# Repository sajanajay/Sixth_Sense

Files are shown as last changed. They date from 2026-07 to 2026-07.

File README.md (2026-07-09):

<div align="center">

# 🚴 Sixth Sense

### Intelligent Rear-Collision Warning System for Cyclists

*A radar-powered embedded safety system that gives cyclists a new sense of awareness through intuitive haptic feedback.*

Github_Cover

**Engineering Design Project**

Department of Electronic & Telecommunication Engineering  
University of Moratuwa







</div>

---

# The Problem

Every cyclist knows the feeling.

You're riding with your eyes fixed ahead.

Then...

A vehicle approaches rapidly from behind.

Do you look over your shoulder?

Do you trust your hearing?

Do you hope nothing is beside you?

That split second of uncertainty is exactly where accidents happen.

**Sixth Sense was created to eliminate that uncertainty.**

---

# Introducing Sixth Sense

Sixth Sense is a radar-assisted cyclist safety system that continuously monitors approaching traffic behind the rider and instantly communicates danger through directional haptic feedback.

Instead of distracting screens or loud warning sounds, the system speaks through touch.

Left side approaching?

👉 Left handlebar vibrates.

Right side approaching?

👉 Right handlebar vibrates.

Directly behind?

👉 Both handlebars respond.

The rider never needs to take their eyes off the road.

---

# Demo

## 🎥 Demo

<p align="center">
  <a href="https://drive.google.com/file/d/1ffC6w6P3MY6zFnOaW4FhN-ex5IwfBISE/view?usp=drive_link">
    Watch Demo
  </a>
</p>

## 🎥 PCB Functionality Testing

<p align="center">
  <a href="https://drive.google.com/drive/folders/12CS2pHYX-PVSih4xlRxphCRVApFPQM8z?usp=sharing">
    Watch Testing
  </a>
</p>

<p align="center">
<b>▶ Click the image above to watch the demonstration</b>
</p>
# Product Showcase

## Complete System

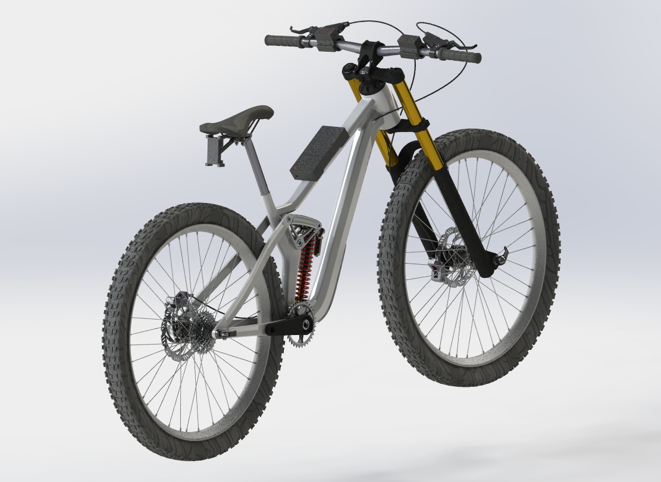
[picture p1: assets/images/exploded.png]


## Mounted on Bicycle

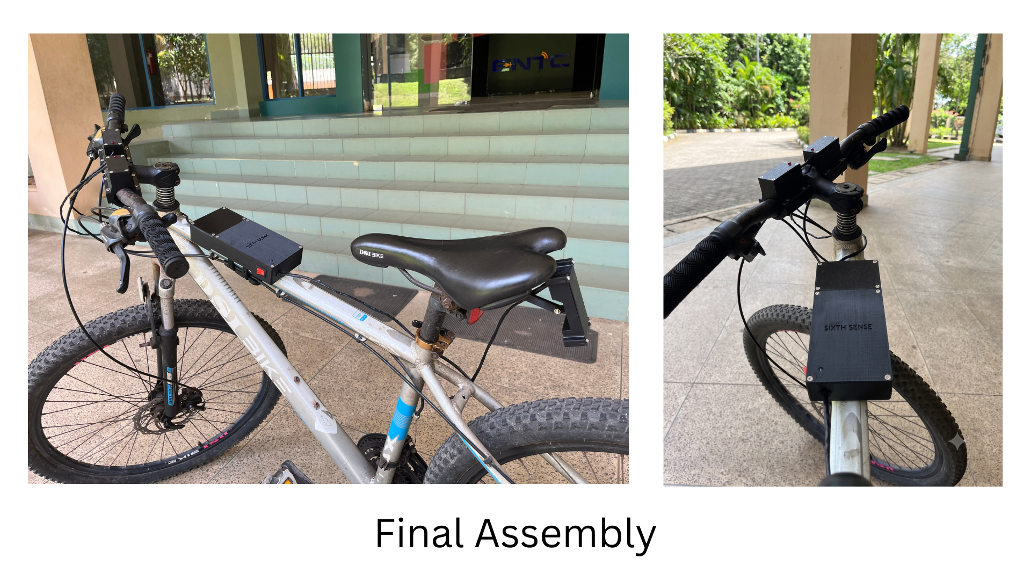
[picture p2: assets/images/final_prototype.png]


# Key Features

✔ 24 GHz FMCW mmWave Radar

✔ Intelligent Rear Vehicle Detection

✔ Real-Time Embedded Processing

✔ Directional Haptic Feedback

✔ Visual LED Warning System

✔ Custom Designed PCB

✔ ESP32 Embedded Platform

✔ Battery Powered

✔ Modular Hardware Design

✔ Custom CAD Enclosures

✔ 3D Printed Prototype

✔ Lightweight Bicycle Integration

# How It Works

```text
          Vehicle

             │

             ▼

      24 GHz Radar Sensor

             │

             ▼

      ESP32 Embedded System

             │

   Threat Evaluation Logic

             │

    ┌────────┴────────┐

    ▼                 ▼

 Left Handle     Right Handle

 Haptic Unit     Haptic Unit

    ▼                 ▼

 Rider receives intuitive tactile warning
```

# System Architecture



# Hardware Overview

## Rear Radar Module

Captures approaching vehicles using 24 GHz FMCW radar technology.

📷

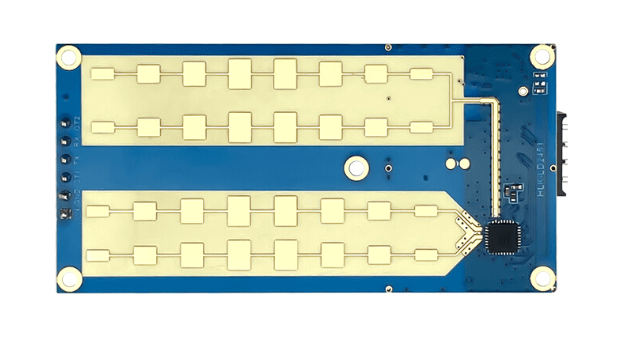
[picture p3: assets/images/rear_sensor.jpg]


## Central Processing Unit

The brain of the system.

Contains

- ESP32
- Custom PCB
- Power Electronics
- Battery
- Firmware

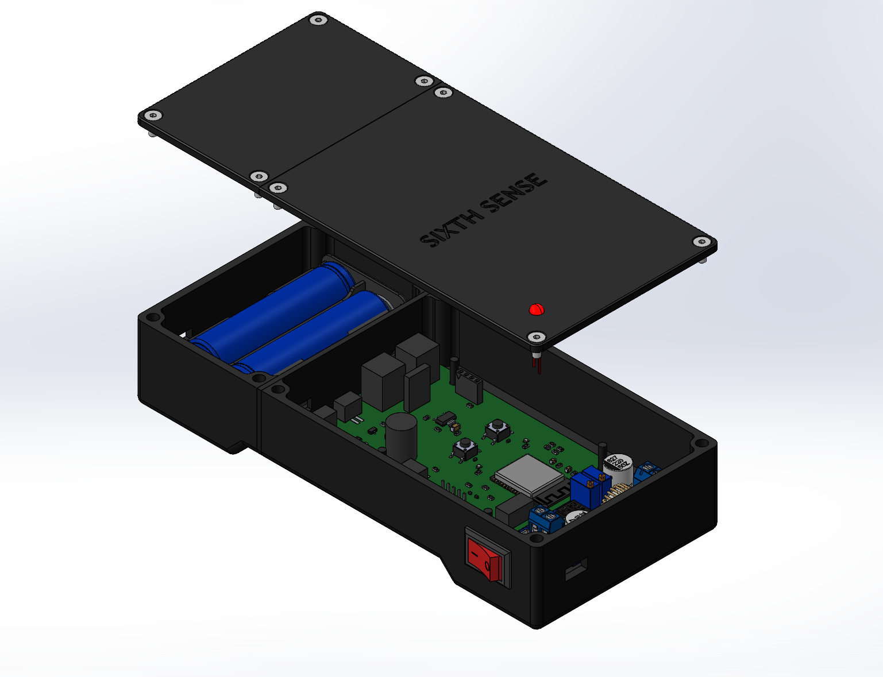
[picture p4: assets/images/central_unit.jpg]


## Haptic Feedback Units

Mounted beside both brake levers to provide intuitive directional warnings.

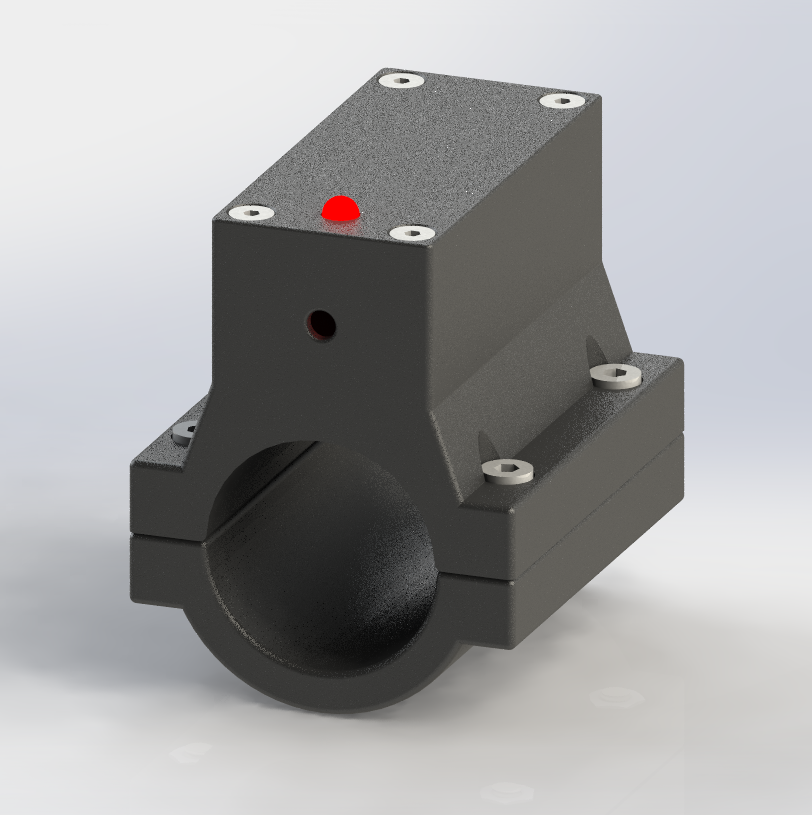
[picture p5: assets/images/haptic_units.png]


# Electronics

## Custom PCB

Professional two-layer PCB designed specifically for Sixth Sense.

### Schematic

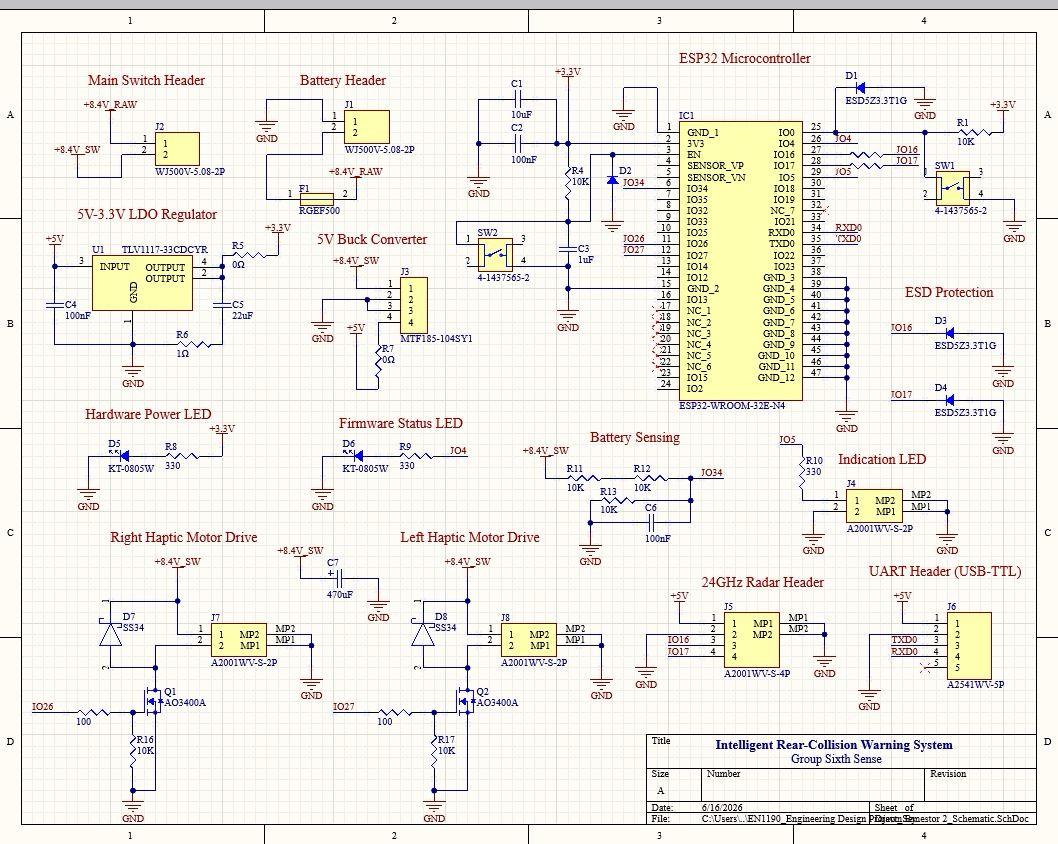
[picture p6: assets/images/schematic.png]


### PCB Layout

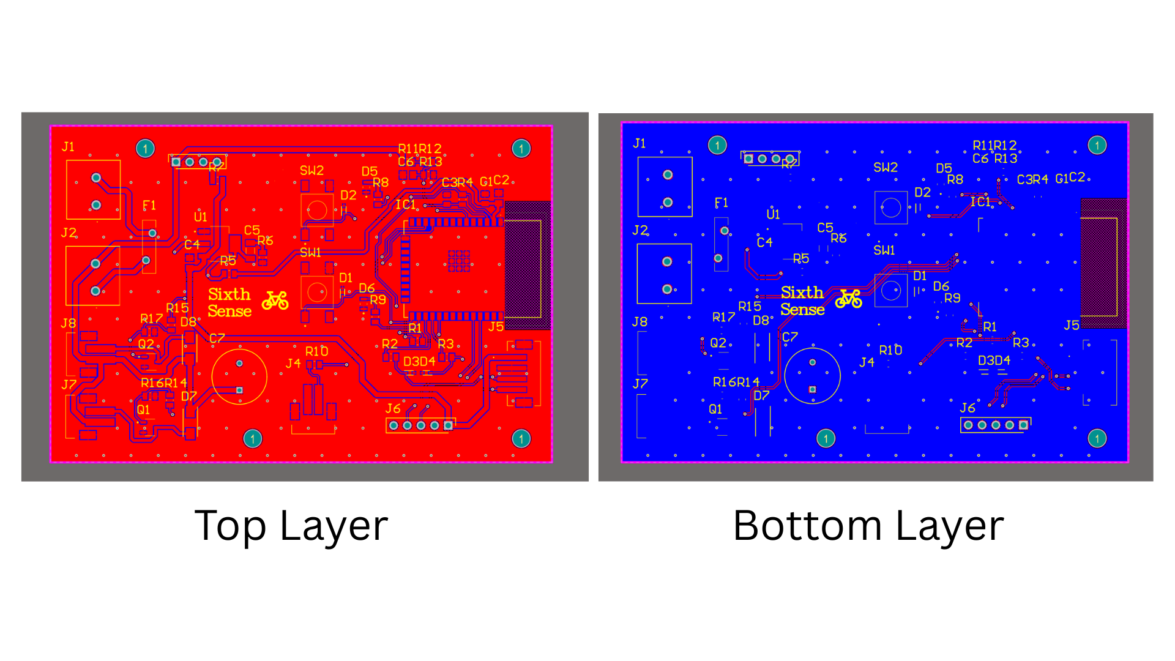
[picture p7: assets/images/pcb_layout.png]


### 3D PCB

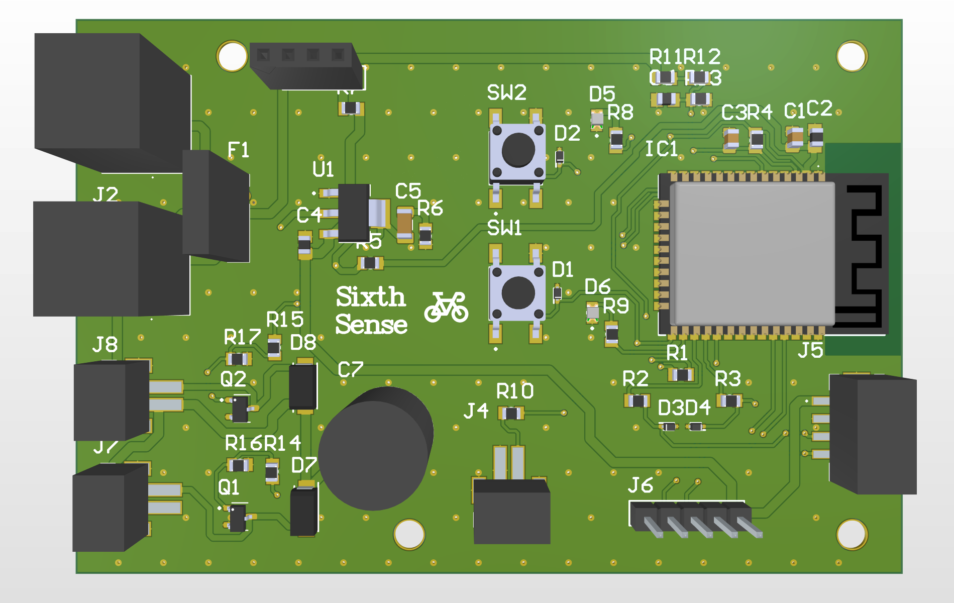
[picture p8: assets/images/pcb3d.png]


# Mechanical Design

Designed completely in **SolidWorks**

## Initial Concepts

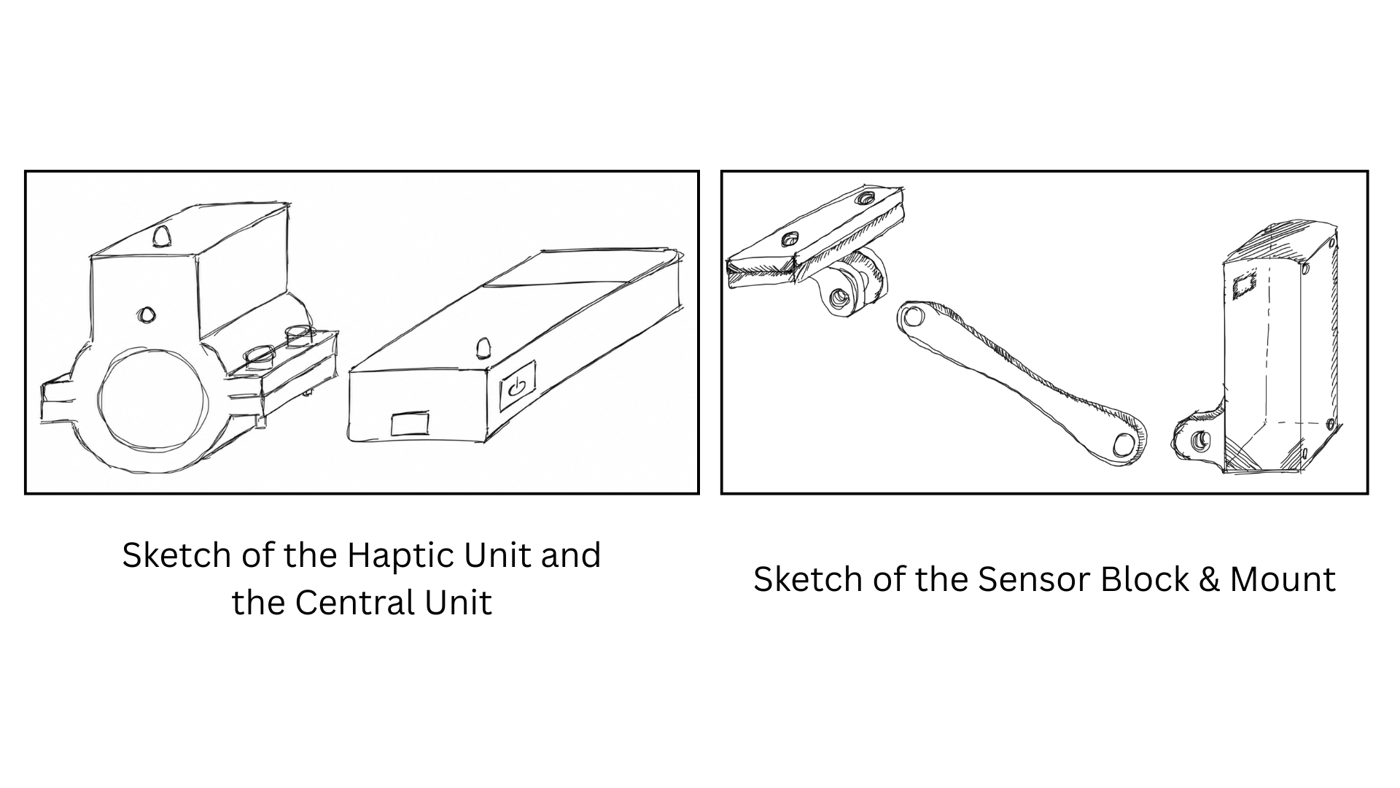
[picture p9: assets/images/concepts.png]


## Engineering Drawings

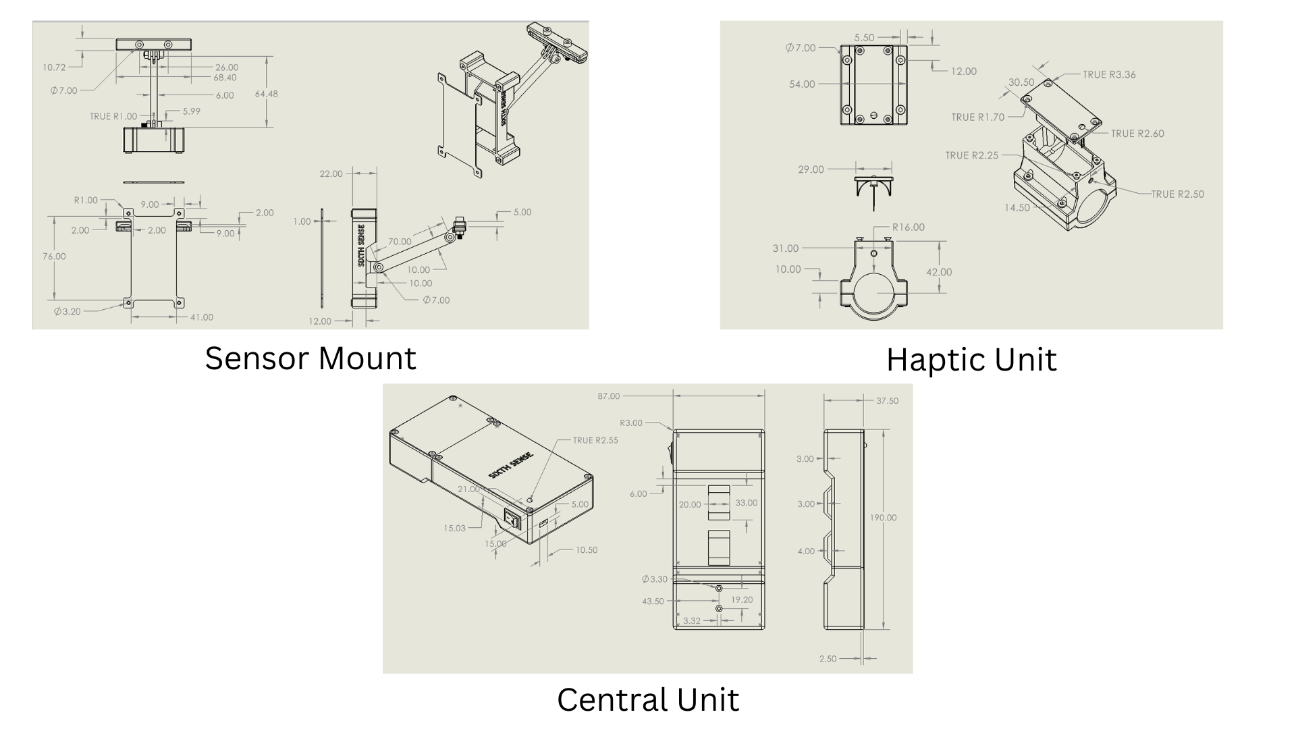
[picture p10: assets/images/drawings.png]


## Exploded Assembly


## CAD Assembly



## Final Assembly



# Built With

| Category | Technology |
|---|---|
| MCU | ESP32 |
| Sensor | 24 GHz mmWave Radar |
| Programming | Arduino C++ |
| PCB | Altium Designer |
| CAD | SolidWorks |
| Manufacturing | 3D Printing |

---

# Repository Structure

```
SixthSense/

│

├── Firmware/
│
├── PCB/
│
├── CAD/
│
├── Documentation/
│
├── assets/
│
├── Images/
│
└── README.md
```

---

# Design Philosophy

Rather than overwhelming cyclists with screens, sounds, and unnecessary distractions...

Sixth Sense quietly augments the rider's natural awareness.

It becomes an extension of instinct.

Not another gadget.

---

# Future Vision

- Smartphone Integration
- Bluetooth Connectivity
- Companion Mobile Application
- USB-C Charging
- Waterproof Housing
- Miniaturized PCB
- AI-based Traffic Behaviour Analysis
- Commercial Manufacturing

---

# Gallery

| | |
|---|---|
|  |  |
|  |  |

---

# Development Team

| Member | Contribution |
|---|---|
| H.R.A.I. Jayasinghe | Electronics • PCB • System Design |
| T.U. Dambarage | Firmware • Algorithms • Mechanical Design |
| S.N. Jayasooriya | PCB • Firmware • Testing |
| A.Y.D. Perera | Schematic Design • Mechanical Design • Assembly |

Team_Sixth_Sense

From Left to Right => A.Y.D. Perera, H.R.A.I. Jayasinghe, T.U. Dambarage,  S.N. Jayasooriya

# Acknowledgements

Department of Electronic and Telecommunication Engineering

University of Moratuwa

Engineering Design Project

---

<div align="center">

## ⭐ If you like this project, consider giving it a Star.

*"Making cycling safer, one vibration at a time."*

</div>

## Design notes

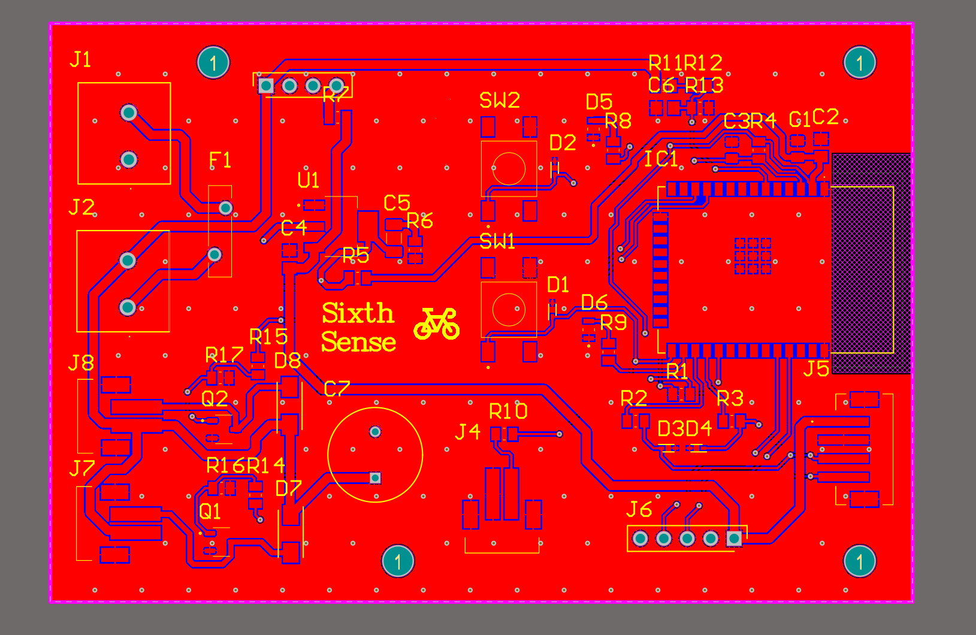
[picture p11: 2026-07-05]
hardware/Images/pcb_top_layer.png

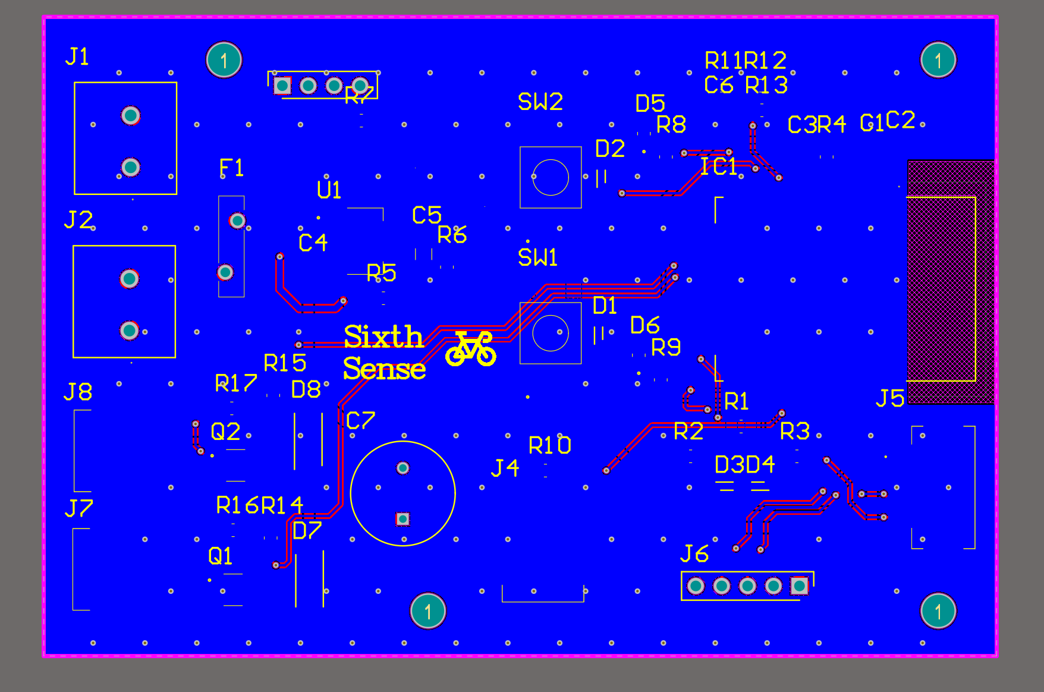
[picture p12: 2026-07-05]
hardware/Images/pcb_bottom_layer.png

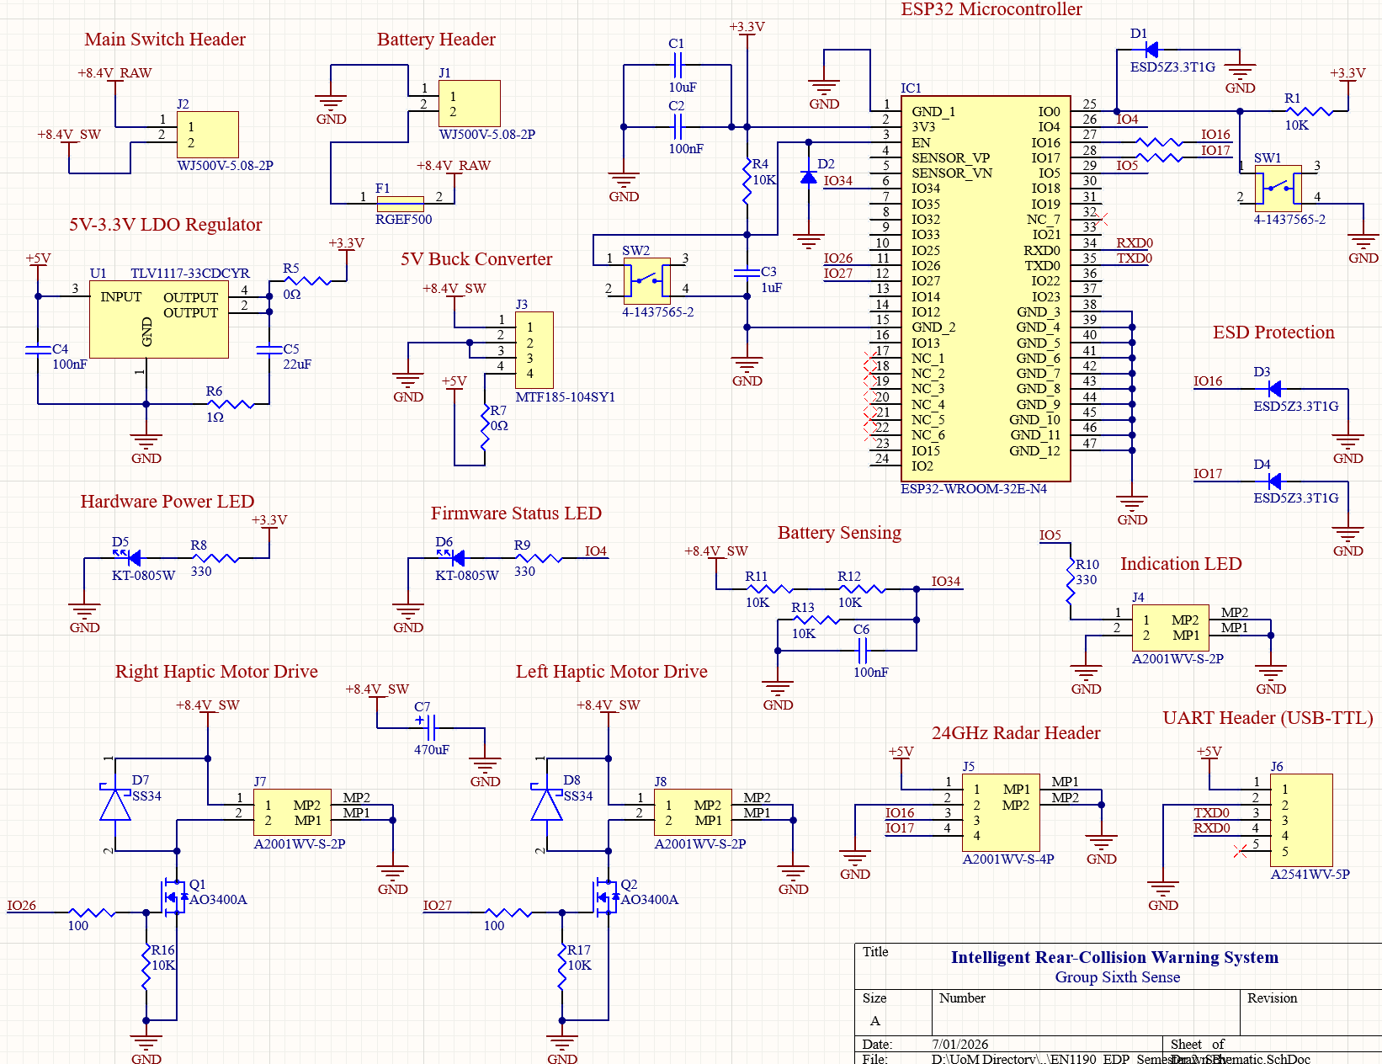
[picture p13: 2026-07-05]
hardware/Images/pcb_schematic.png

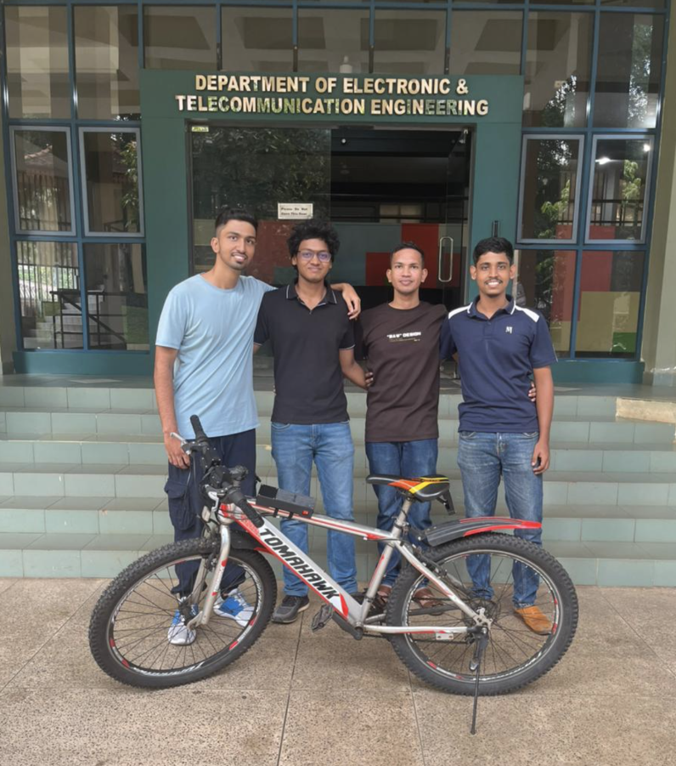
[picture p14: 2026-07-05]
media/Photos/team_sixth_sense.png

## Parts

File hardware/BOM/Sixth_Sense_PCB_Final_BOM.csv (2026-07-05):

Name | Description | Designator | Footprint | LibRef | Quantity | LCSC Part Number
MTF185-104SY1 | Female Header 4 Position 2.54mm Pitch Single Row Through Hole |  | RHDR4W64P0X254_1X4_1041X250X865P | MTF185-104SY1 | 1 | C358718
10uF | 10uF ±10% 25V Ceramic Capacitor X5R 0805 | C1 | CAPC2012X145N | CL21A106KAYNNNE | 1 | C15850
100nF | 100nF ±10% 50V Ceramic Capacitor X7R 0805 | C2, C4, C6 | CAPC2012X70 | CC0805KRX7R9BB104 | 3 | C49678
1uF | 1uF ±10% 50V Ceramic Capacitor X7R 0805 | C3 | CAPC2012X135N | CL21B105KBFNNNE | 1 | C28323
22uF | 22uF ±10% 16V Ceramic Capacitor X5R 1206 | C5 | CAPC3216X180N | CL31A226KOHNNNE | 1 | C90146
470uF | 470uF 25V Aluminum Electrolytic Capacitors Through Hole,D10xL12.5mm 10000hrs@105? | C7 | CAPPRD500W60D1025H1400 | 25YXJ470M10X12.5 | 1 | C88740
ESD5Z3.3T1G | 14.1VC Clamp 11.2A Ipp TVS DIODE SOD-523 | D1, D2, D3, D4 | SODFL1608X70N | ESD5Z3.3T1G | 4 | C61148
KT-0805W | White LED Indication - Discrete 2.6V~3.2V 0805 | D5, D6 | LED_KT-0805W | KT-0805W | 2 | C34499
SS34 | Diode Independent 40V 3A Surface Mount SMA(DO-214AC) | D7, D8 | DIOM5127X241N | SS34 SMA | 2 | C8678
RGEF500 | Polymeric PTC Resettable Fuse 16V 5A Through Hole P=5.08mm | F1 | RGEF500 | RGEF500 | 1 | C468988
ESP32-WROOM-32E-N4 | 2.4GHz On-board PCB Antenna -98dBm SMD,25.5x18mm RF Transceiver Modules and Modems RoHS | IC1 | ESP32WROOM32EN4 | ESP32-WROOM-32E-N4 | 1 | C701341
WJ500V-5.08-2P | 2 Position Wire to Board Terminal Block Through Hole 5.08mm | J1, J2 | WJ500V5082P | WJ500V-5.08-2P | 2 | C8465
A2001WV-S-2P | Connector Header 2 position 2mm Pitch | J4, J7, J8 | A2001WVS2P | A2001WV-S-2P | 3 | C225226
A2001WV-S-4P | Connector Header 4 position 2mm Pitch | J5 | A2001WVS4P | A2001WV-S-4P | 1 | C225228
A2541WV-5P | Pin Header 5 Position 2.54mm Pitch Single Row Through Hole -40?~+105? | J6 | HDRV5W64P0X254_1X5_1270X254X899P | A2541WV-5P | 1 | C225480
AO3400A | N-Channel 30 V 5.7A (Ta) 1.4W (Ta) Surface Mount SOT-23-3 | Q1, Q2 | SOT95P280X125-3N | AO3400A | 2 | C20917
10K | 10kO ±1% 125mW 0805 Thick Film Resistor | R1, R4, R11, R12, R13, R16, R17 | RESC2012X65N | 0805W8F1002T5E | 7 | C17414
0O | 0O ±1% 125mW 0805 Thick Film Resistor | R2, R3, R5, R7 | RESC2012X65N | 0805W8F0000T5E | 4 | C17477
1O | 1O ±1% 125mW 0805 Thick Film Resistor | R6 | RESC2012X65N | 0805W8F100KT5E | 1 | C25271
330 | 330O ±1% 125mW 0805 Thick Film Resistor | R8, R9, R10 | RESC2012X65N | 0805W8F3300T5E | 3 | C17630
100 | 100O ±1% 125mW 0805 Thick Film Resistor | R14, R15 | RESC2012X65N - duplicate | 0805W8F1000T5E | 2 | C17408
4-1437565-2 | Switch Tactile OFF (ON) SPST Round Button Gull Wing 0.05A 24VDC 1VA 9.18N SMD T/R | SW1, SW2 | SW_4-1437565-2 | 4-1437565-2 | 2 | C2680629
TLV1117-33CDCYR | 3.3V 15V Positive Fixed SOT-223 Voltage Regulators - Linear, Low Drop Out (LDO) Regulators RoHS | U1 | SOT230P700X180-4N | TLV1117-33CDCYR | 1 | C91728

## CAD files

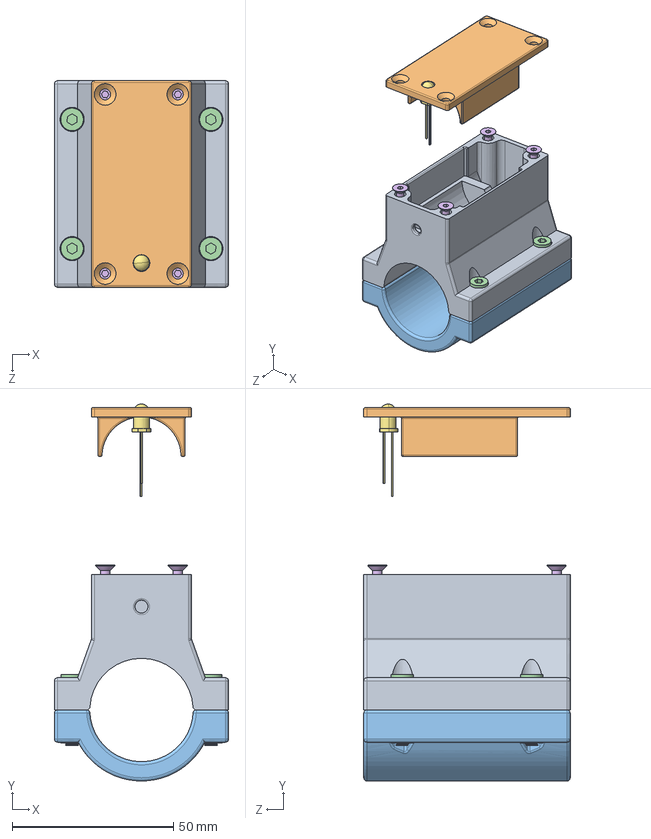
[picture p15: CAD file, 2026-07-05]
mechanical/CAD/Front_Unit/Front.SLDASM
54.0 x 116.8 x 64.0 mm
front_upper_clamp
front_clamp_lid
front_lower_clamp
M4x18.stp x 4
nut_m4.stp x 4
hex_socket_button_head_M3x08.step x 4
red-led-5mm.step

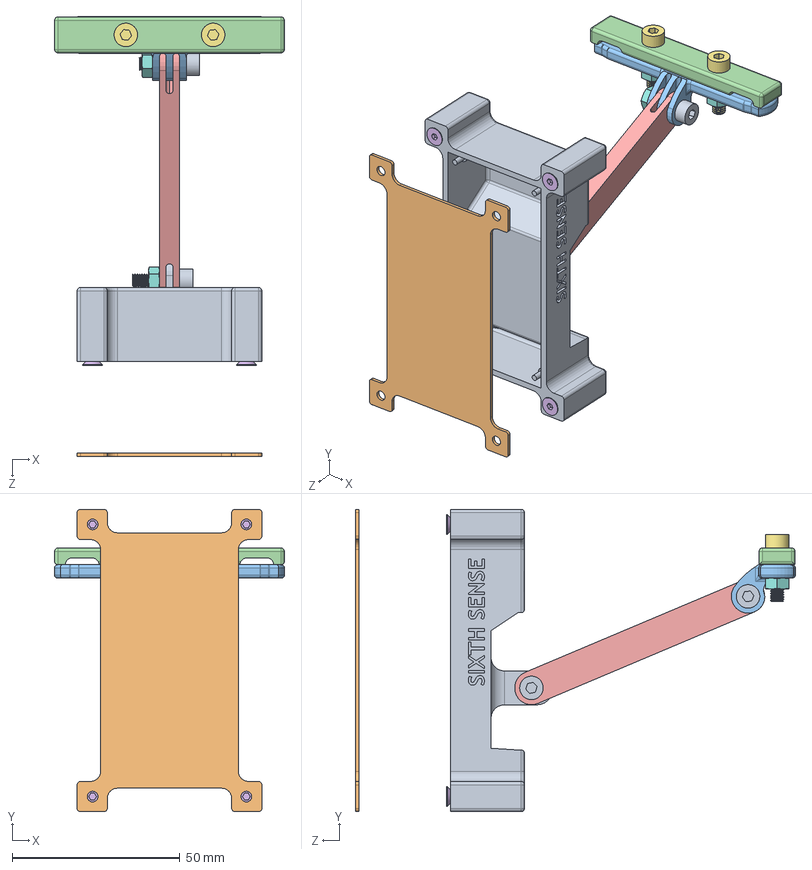
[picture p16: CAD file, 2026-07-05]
mechanical/CAD/Rear_Unit/Rear.SLDASM
68.6 x 90.0 x 131.0 mm
sensor_casing
sensor_casing_lid
rear_mount_lower
rear_mount_upper
rear_mount_lever
hex_socket_button_head_M3x08.step x 4
M4x16.stp x 2
nut_m4.stp x 4
M4x14.stp x 2

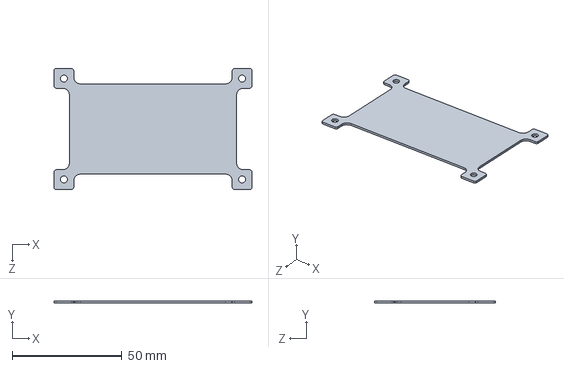
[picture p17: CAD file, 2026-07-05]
mechanical/CAD/Rear_Unit/sensor_casing_lid.SLDPRT
90.0 x 1.00 x 55.0 mm

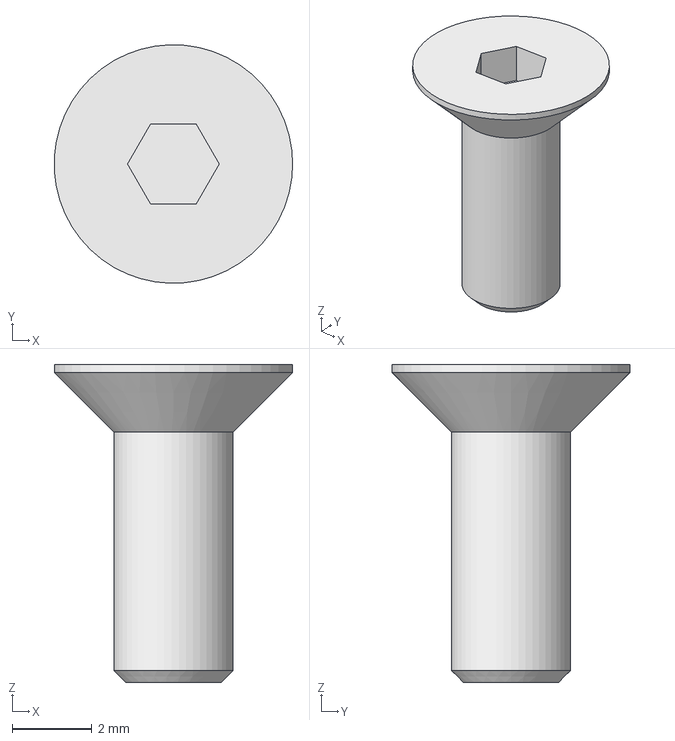
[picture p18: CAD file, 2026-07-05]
mechanical/CAD/Central_Unit/hex_socket_button_head_M3x08.step
5.99 x 6.00 x 8.00 mm

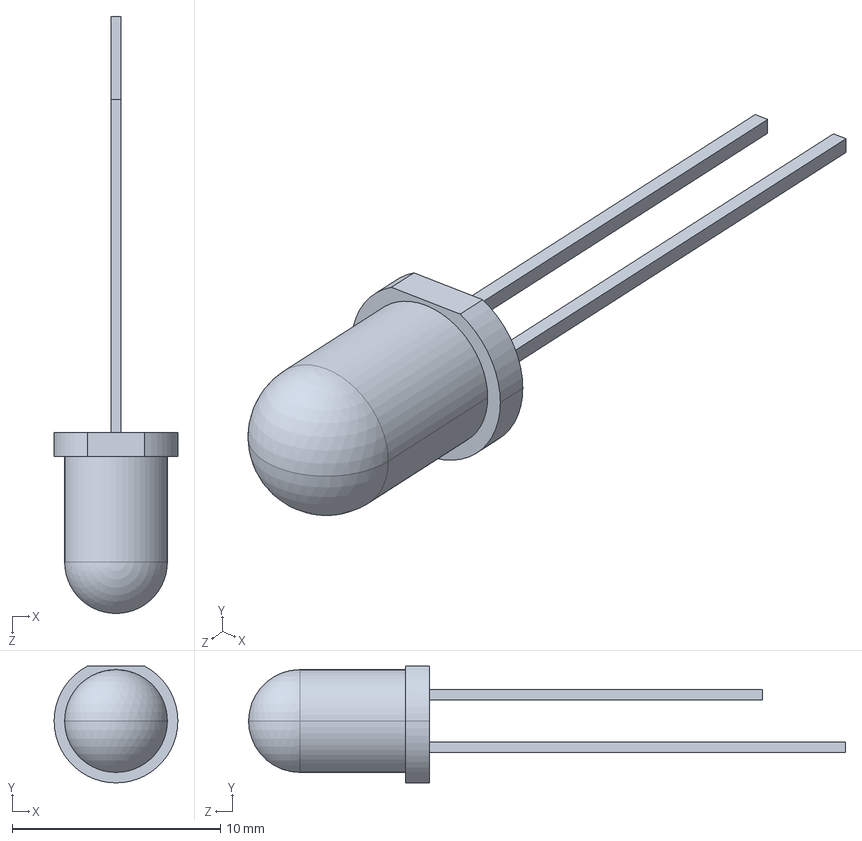
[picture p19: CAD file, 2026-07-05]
mechanical/CAD/Front_Unit/red-led-5mm.STEP
5.95 x 5.62 x 28.7 mm

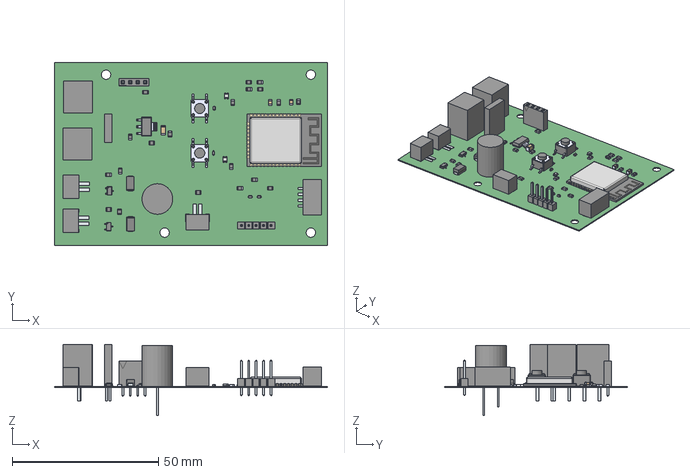
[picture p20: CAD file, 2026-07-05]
mechanical/CAD/Central_Unit/EN1190_Engineering Design Project_Semestor 2_PCB.step
93.3 x 62.6 x 24.4 mm

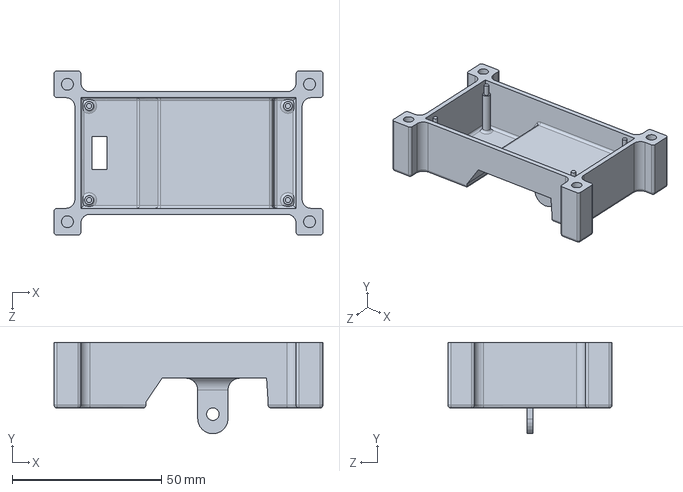
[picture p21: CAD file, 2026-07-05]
mechanical/CAD/Rear_Unit/sensor_casing.SLDPRT
90.0 x 30.6 x 55.0 mm

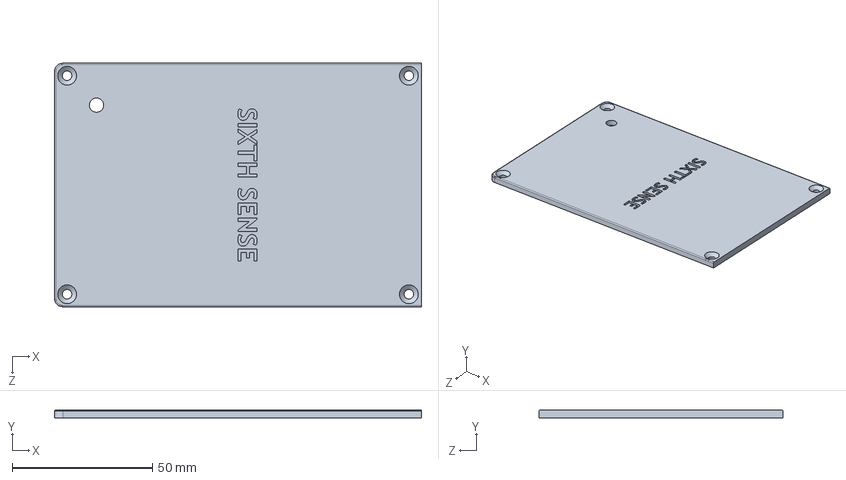
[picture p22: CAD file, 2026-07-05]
mechanical/CAD/Central_Unit/central_pcb_lid.SLDPRT
131.0 x 3.00 x 87.0 mm

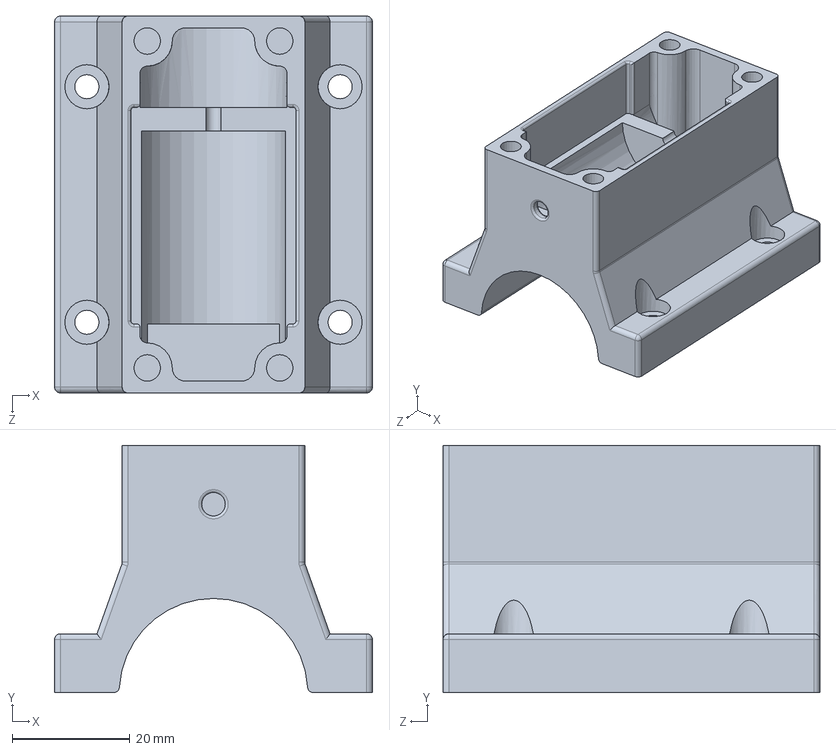
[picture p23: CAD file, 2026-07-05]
mechanical/CAD/Front_Unit/front_upper_clamp.SLDPRT
54.0 x 42.0 x 64.0 mm

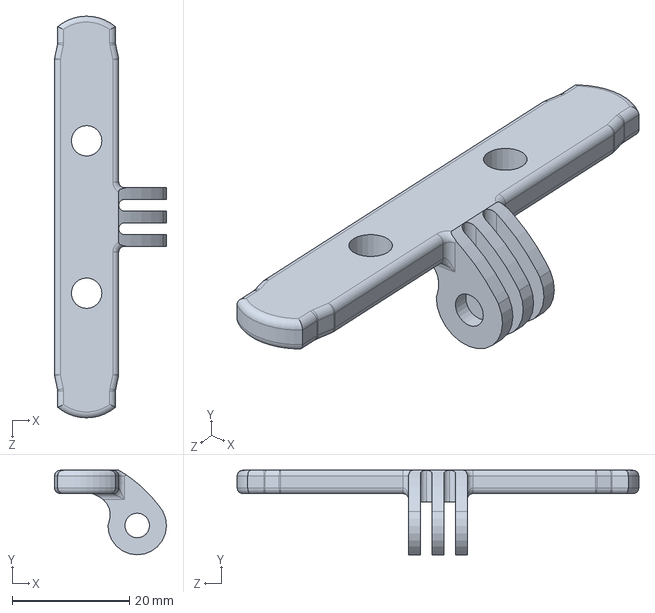
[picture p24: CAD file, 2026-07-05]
mechanical/CAD/Rear_Unit/rear_mount_lower.SLDPRT
19.1 x 14.4 x 68.6 mm

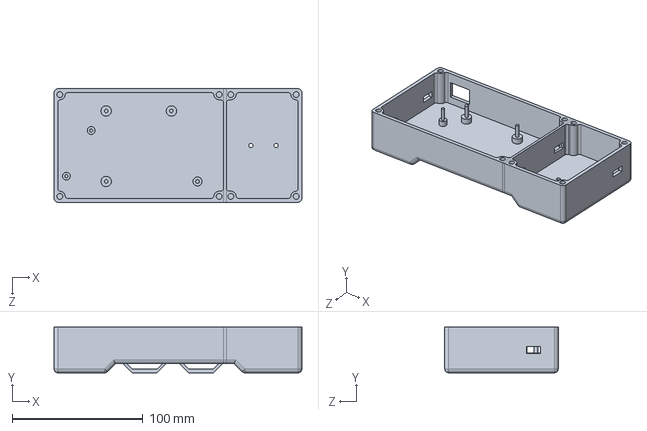
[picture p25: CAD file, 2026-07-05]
mechanical/CAD/Central_Unit/central_unit.SLDPRT
190.0 x 35.0 x 87.0 mm

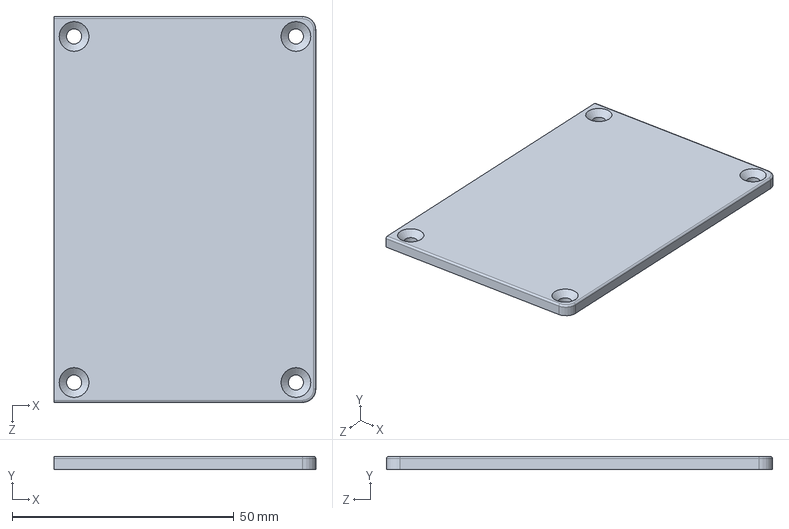
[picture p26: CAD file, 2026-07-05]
mechanical/CAD/Central_Unit/central_battery_lid.SLDPRT
59.0 x 3.00 x 87.0 mm

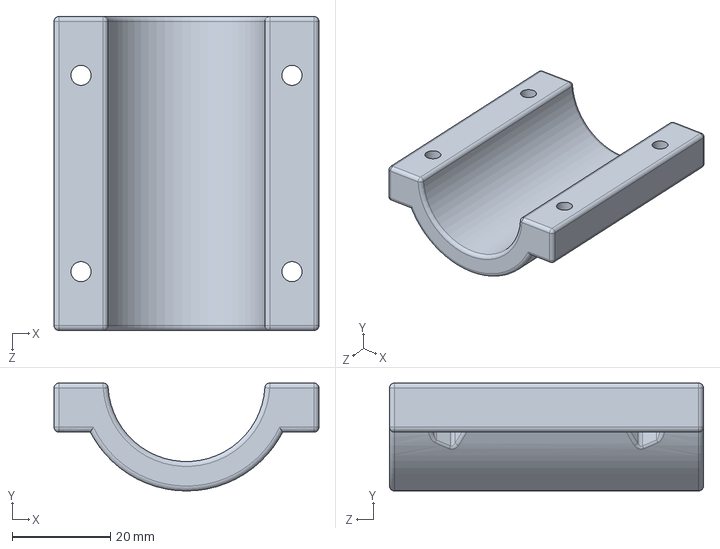
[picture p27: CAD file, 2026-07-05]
mechanical/CAD/Front_Unit/front_lower_clamp.SLDPRT
54.0 x 22.0 x 64.0 mm

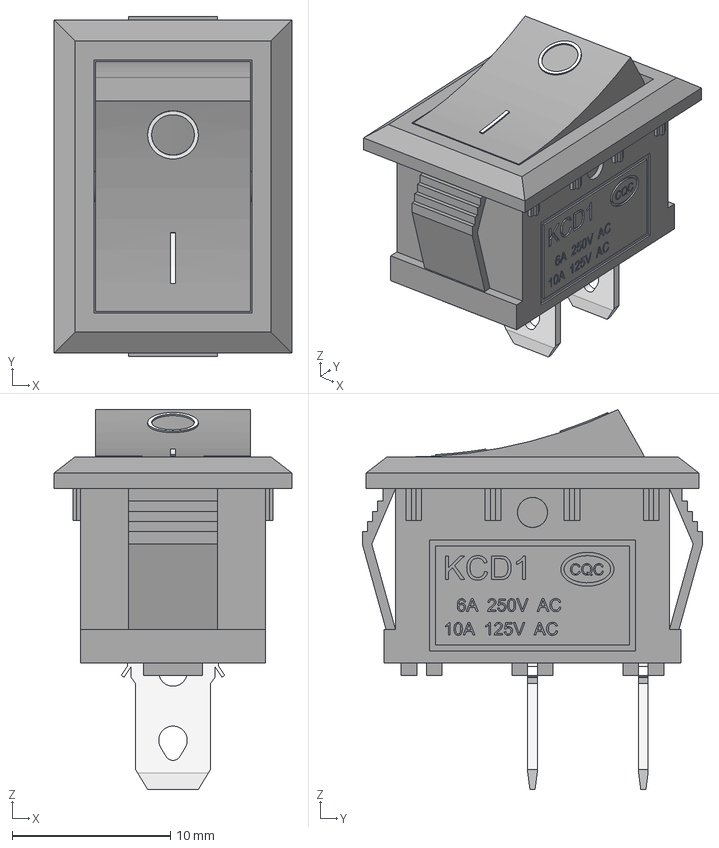
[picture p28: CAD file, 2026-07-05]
mechanical/CAD/Central_Unit/kcd1_a.step
15.0 x 21.5 x 24.0 mm
Blade_001
Blade_002
Base_w_text
knob001

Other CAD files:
mechanical/CAD/Rear_Unit/rear_mount_upper.SLDPRT
mechanical/CAD/Central_Unit/18650.stp
mechanical/CAD/Central_Unit/Central.SLDDRW
mechanical/CAD/Central_Unit/batteryCase18650x2.step
mechanical/CAD/Front_Unit/Front.SLDDRW
mechanical/CAD/Front_Unit/M4x18.stp
mechanical/CAD/Front_Unit/front_clamp_lid.SLDPRT
mechanical/CAD/Front_Unit/nut_m4.stp
mechanical/CAD/Rear_Unit/M4x14.stp
mechanical/CAD/Rear_Unit/M4x16.stp
mechanical/CAD/Rear_Unit/Rear.SLDDRW
mechanical/CAD/Rear_Unit/nut_m4.stp
mechanical/CAD/Rear_Unit/rear_mount_lever.SLDPRT

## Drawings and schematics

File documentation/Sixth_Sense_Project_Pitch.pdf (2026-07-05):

# INTELLIGENT REAR-COLLISION WARNING

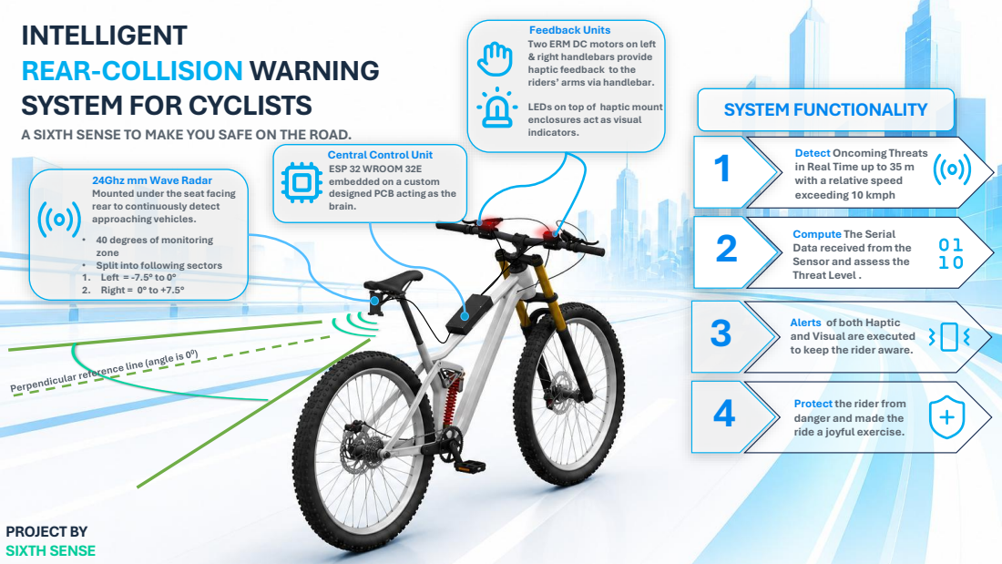
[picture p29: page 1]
PROJECT BY SIXTH SENSE; SYSTEM FUNCTIONALITY

Feedback Units
Two ERM DC motors on left
& right handlebars provide
haptic feedback to the
riders’ arms via handlebar.

SYSTEM FOR CYCLISTS

LEDs on top of haptic mount
enclosures act as visual
indicators.

A SIXTH SENSE TO MAKE YOU SAFE ON THE ROAD.

Detect Oncoming Threats
in Real Time up to 35 m
with a relative speed
exceeding 10 kmph

Central Control Unit
ESP 32 WROOM 32E
embedded on a custom
designed PCB acting as the
brain.

24Ghz mm Wave Radar
Mounted under the seat facing
rear to continuously detect
approaching vehicles.
• 40 degrees of monitoring
zone
• Split into following sectors
1. Left = -7.5° to 0°
2. Right = 0° to +7.5°

Compute The Serial
Data received from the
Sensor and assess the
Threat Level .

and Visual are executed 3 to keep the rider aware.

Alerts of both Haptic

danger and made the 4

Protect the rider from

ride a joyful exercise.

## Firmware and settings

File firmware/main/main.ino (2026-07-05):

// Importing Necessary Libraries (Header Files)
#include <Arduino.h>

// Specififc Library designed for acceses to Watchdog Timer in ESP32

#include <esp_task_wdt.h>  

//Purpose of the WDT is reset the system if the firmware becomes unresponsive.


// GPIO Pin Allocation for Radar Sensor 

/* !!!Notice!!!
    Radar TX ----> Defined ESP 32 RX GPIO Pin
    Radar RX ----> Defined ESP 32 TX GPIO Pin

    Above crossing is the fundamental behavior of serial communication

*/

#define RADAR_RX 16  // JO16 
#define RADAR_TX 17  // JO17

// GPIO Pins Allocation for Motor Control (MOSFET Controlled DC Motors)
#define MOTOR_RIGHT_PIN 26 // IO26 (Right Haptic - MOTOR_1)
#define MOTOR_LEFT_PIN 27  // IO27 (Left Haptic - MOTOR_2)

// Pin Allocation for Indication LEDs & Analog Battery Voltage Sensing Input
#define FIRMWARE_LED_PIN 4   // JO4 (Onboard D6)
#define INDICATION_LED_PIN 5 // JO5 (External Header J4)
#define BATTERY_ADC_PIN 34   // JO34

// PWM Settings used to Control the Intensity of the ERM Haptic Motors.
#define PWM_FREQ 1000 // 1000 pulses per seconds, T-period = 1ms     
#define PWM_RES 8
  // level count = 256 value range 0-255
  // value 0 (0% Power) --> always off    value 255 (100% Power) --> always on
  
#define PWM_DUTY_50 127   // 50% power (Used in Initialization)
  
  // Higher the threat higher the intensity of the vibration
#define PWM_DUTY_40 102   // 40% power (FAST Vehicles: >= 10 km/h)
#define PWM_DUTY_20 51    // 20% power (SLOW Vehicles: 5 to 9 km/h)
#define PWM_DUTY_0 0      // 0% power (Off)

// Battery Sensing Configuration
/*
    V = ADC * (Vref / 4096) * ((R1+R2)/R2)
      = ADC * (3.3/4096) * ((20K+10K)/10K) = ADC * 0.002417
*/
const float VOLTAGE_MULTIPLIER = 0.002417;
const float LOW_BATT_THRESHOLD = 6.2;

//#define DEBUG - Used during the build to print the parameters(speed, distacne , etc...)
// in serial montor

// Initialize a dediacted UART2 Serial Interface to Communicate with Radar
HardwareSerial RadarSerial(2);

// Assignin Radar Protocol Constants to an Array
const byte HEADER[4] = {0xF4, 0xF3, 0xF2, 0xF1};
const byte FOOTER[4] = {0xF8, 0xF7, 0xF6, 0xF5};

// Parser Variables
enum ParserState { SYNC_HEADER, READ_LENGTH, READ_PAYLOAD, SYNC_FOOTER };
ParserState currentState = SYNC_HEADER;
int headerIndex = 0;
int footerIndex = 0;
uint16_t payloadLength = 0;
int payloadIndex = 0;
byte payload[128]; // FIX: Increased from 64 — LD2451 multi-target frames can exceed 64 bytes
bool payloadValid = false; // FIX: Track whether current payload is fresh and complete

// Directional Speed-Based State Machine
enum ThreatZone { CLEAR = 0, SLOW = 1, FAST = 2 };
ThreatZone previousLeftZone  = CLEAR;
ThreatZone previousRightZone = CLEAR;

// FIX: Independent confidence counters per zone — a left-side burst no longer gates the right motor
int leftConfidenceCounter  = 0;
int rightConfidenceCounter = 0;
const int REQUIRED_HITS    = 2;   // Target must persist for 2 frames before triggering
const int CONFIDENCE_CAP   = 5;   // Maximum counter value
const int MIN_THREAT_SPEED = 5;   // Ignore micro-vibrations under 5 km/h

// Independent Non-Blocking Motor Timer Variables (250ms "Single Tap")
const unsigned long MOTOR_DURATION   = 250;
unsigned long leftMotorStartTime     = 0;
bool leftMotorActive                 = false;
unsigned long rightMotorStartTime    = 0;
bool rightMotorActive                = false;

// Sustained-threat re-pulse: re-alert rider if threat persists at same level
const unsigned long REPULSE_INTERVAL = 1000; // Re-fire every 1s for sustained threats
unsigned long lastLeftPulseTime      = 0;
unsigned long lastRightPulseTime     = 0;

// Non-Blocking Firmware LED Pulse Variables
const unsigned long FW_LED_DURATION = 100; // milliseconds
unsigned long fwLedStartTime        = 0;
bool fwLedActive                    = false;

// Non-Blocking Indication LED Blink Variables
unsigned long lastBlinkTime         = 0;
const unsigned long BLINK_INTERVAL  = 500; // 500ms low-voltage toggle
bool indicationLedState             = false;

// Battery Polling Timer
unsigned long lastBatteryCheck           = 0;
const unsigned long BATT_CHECK_INTERVAL  = 1000; // Sample battery every 1s
float currentVoltage                     = 8.4;

// ---------------------------------------------------------
// SETUP
// ---------------------------------------------------------
void setup() {
  Serial.begin(921600);
  RadarSerial.begin(115200, SERIAL_8N1, RADAR_RX, RADAR_TX);

  // Watchdog timer — 5 second timeout (IDF 5.x / Arduino Core 3.x API)
  // Resets the chip if loop() ever stalls, critical for a safety wearable
  esp_task_wdt_config_t wdt_config = {
    .timeout_ms    = 5000,
    .idle_core_mask = 0,
    .trigger_panic = true
  };
  esp_task_wdt_reconfigure(&wdt_config);
  esp_task_wdt_add(NULL);

  // Initialize ESP32 V3 Hardware PWM for Motors
  ledcAttach(MOTOR_RIGHT_PIN, PWM_FREQ, PWM_RES);
  ledcAttach(MOTOR_LEFT_PIN, PWM_FREQ, PWM_RES);

  // Initialize LED Pins
  pinMode(FIRMWARE_LED_PIN, OUTPUT);
  pinMode(INDICATION_LED_PIN, OUTPUT);
  digitalWrite(FIRMWARE_LED_PIN, LOW);
  digitalWrite(INDICATION_LED_PIN, HIGH); // Solid ON when powered

  analogReadResolution(12); // Setup ADC range (0-4095)

  Serial.println("System Booting...");

  // ---------------------------------------------------------
  // HARDWARE HAPTIC SELF-TEST (250ms Buzz on Power Up)
  // ---------------------------------------------------------
  Serial.println("Executing Haptic Self-Test...");
  ledcWrite(MOTOR_LEFT_PIN, PWM_DUTY_50);
  ledcWrite(MOTOR_RIGHT_PIN, PWM_DUTY_50);
  delay(250);
  ledcWrite(MOTOR_LEFT_PIN, PWM_DUTY_0);
  ledcWrite(MOTOR_RIGHT_PIN, PWM_DUTY_0);
  Serial.println("Self-Test Complete.");

  // Flush any radar data that accumulated in the buffer during the 250ms delay
  while (RadarSerial.available()) {
    RadarSerial.read();
  }

  Serial.println("System Initialized: Directional Velocity Logic Active (250ms Tap).");
}

// ---------------------------------------------------------
// BATTERY & INDICATION LED
// ---------------------------------------------------------
void checkBatteryAndIndication() {
  // FIX: Snapshot millis() once to avoid non-deterministic double-call
  unsigned long now = millis();

  if (now - lastBatteryCheck >= BATT_CHECK_INTERVAL) {
    int rawADC = analogRead(BATTERY_ADC_PIN);
    currentVoltage = rawADC * VOLTAGE_MULTIPLIER;
    lastBatteryCheck = now;
  }

  if (currentVoltage < LOW_BATT_THRESHOLD) {
    if (millis() - lastBlinkTime >= BLINK_INTERVAL) {
      indicationLedState = !indicationLedState;
      digitalWrite(INDICATION_LED_PIN, indicationLedState);
      lastBlinkTime = millis();
    }
  } else {
    digitalWrite(INDICATION_LED_PIN, HIGH);
    indicationLedState = true;
  }
}

// ---------------------------------------------------------
// CORE THREAT EVALUATION
// ---------------------------------------------------------
void evaluateTargetThreat() {

 
  if (!payloadValid || payloadLength == 0) {
    
    if (leftConfidenceCounter  > 0) leftConfidenceCounter--;
    if (rightConfidenceCounter > 0) rightConfidenceCounter--;
    return;
  }
  payloadValid = false; 
  byte targetCount = payload[0];
  ThreatZone currentLeftZone  = CLEAR;
  ThreatZone currentRightZone = CLEAR;
  bool validLeftThreat  = false;
  bool validRightThreat = false;

  for (int i = 0; i < targetCount; i++) {
    int baseIdx = 2 + (i * 5);
    if (baseIdx + 4 >= (int)payloadLength) break;

    
    int angle      = (int)payload[baseIdx] - 128;
    byte direction = payload[baseIdx + 2];
    byte speed_kmh = payload[baseIdx + 3];

    if (direction == 0x01 && speed_kmh >= MIN_THREAT_SPEED) {
      ThreatZone targetThreatLevel = (speed_kmh >= 10) ? FAST : SLOW;

      
      bool isLeft   = (angle > 7.5);
      bool isRight  = (angle < -7.5);
      bool isCentre = (angle >= -7.5 && angle <= 7.5);

      if (isLeft || isCentre) {
        if (targetThreatLevel > currentLeftZone) currentLeftZone = targetThreatLevel;
        validLeftThreat = true;
      }
      if (isRight || isCentre) {
        if (targetThreatLevel > currentRightZone) currentRightZone = targetThreatLevel;
        validRightThreat = true;
      }
    }
  }

  // ---------------------------------------------------------
  // FIX: INDEPENDENT "LEAKY BUCKET" COUNTERS PER ZONE
  // A cluster of left-side targets no longer pre-gates the right motor
  // ---------------------------------------------------------
  if (validLeftThreat) {
    leftConfidenceCounter++;
    if (leftConfidenceCounter > CONFIDENCE_CAP) leftConfidenceCounter = CONFIDENCE_CAP;
  } else {
    if (leftConfidenceCounter > 0) leftConfidenceCounter--;
    if (leftConfidenceCounter < REQUIRED_HITS) currentLeftZone = CLEAR;
  }

  if (validRightThreat) {
    rightConfidenceCounter++;
    if (rightConfidenceCounter > CONFIDENCE_CAP) rightConfidenceCounter = CONFIDENCE_CAP;
  } else {
    if (rightConfidenceCounter > 0) rightConfidenceCounter--;
    if (rightConfidenceCounter < REQUIRED_HITS) currentRightZone = CLEAR;
  }

  // ---------------------------------------------------------
  // EXECUTE 250ms "SINGLE TAP" HAPTICS (Only on Escalation)
  // ---------------------------------------------------------
  bool triggeredNewEvent = false;

  // FIX: Only update previousZone when confidence is met — sub-threshold detections
  // no longer silently advance the baseline and eat the next real escalation
  if (leftConfidenceCounter >= REQUIRED_HITS) {
    bool escalated  = (currentLeftZone > previousLeftZone);
    bool repulse    = (currentLeftZone != CLEAR && currentLeftZone == previousLeftZone &&
                       millis() - lastLeftPulseTime >= REPULSE_INTERVAL);
    if (escalated || repulse) {
      int dutyCycle = (currentLeftZone == FAST) ? PWM_DUTY_40 : PWM_DUTY_20;
      ledcWrite(MOTOR_LEFT_PIN, dutyCycle);
      leftMotorStartTime = millis();
      leftMotorActive    = true;
      lastLeftPulseTime  = millis();
      triggeredNewEvent  = true;
#ifdef DEBUG
      Serial.printf(">>> LEFT TAP  | Speed Tier: %d | PWM: %d | %s <<<\n",
                    currentLeftZone, dutyCycle, escalated ? "ESCALATION" : "SUSTAINED");
#endif
    }
    previousLeftZone = currentLeftZone;
  }

  if (rightConfidenceCounter >= REQUIRED_HITS) {
    bool escalated  = (currentRightZone > previousRightZone);
    bool repulse    = (currentRightZone != CLEAR && currentRightZone == previousRightZone &&
                       millis() - lastRightPulseTime >= REPULSE_INTERVAL);
    if (escalated || repulse) {
      int dutyCycle = (currentRightZone == FAST) ? PWM_DUTY_40 : PWM_DUTY_20;
      ledcWrite(MOTOR_RIGHT_PIN, dutyCycle);
      rightMotorStartTime = millis();
      rightMotorActive    = true;
      lastRightPulseTime  = millis();
      triggeredNewEvent   = true;
#ifdef DEBUG
      Serial.printf(">>> RIGHT TAP | Speed Tier: %d | PWM: %d | %s <<<\n",
                    currentRightZone, dutyCycle, escalated ? "ESCALATION" : "SUSTAINED");
#endif
    }
    previousRightZone = currentRightZone;
  }

  if (triggeredNewEvent) {
    digitalWrite(FIRMWARE_LED_PIN, HIGH);
    fwLedStartTime = millis();
    fwLedActive    = true;
  }
}

// ---------------------------------------------------------
// MAIN LOOP
// ---------------------------------------------------------
void loop() {
  // Feed the watchdog — if we ever fail to reach here within 5s, the WDT resets the chip
  esp_task_wdt_reset();

  // 1. Run Battery Diagnostic
  checkBatteryAndIndication();

  // 2. Manage Independent 250ms Motor Duration Timeouts
  if (leftMotorActive) {
    if (millis() - leftMotorStartTime >= MOTOR_DURATION) {
      ledcWrite(MOTOR_LEFT_PIN, PWM_DUTY_0);
      leftMotorActive = false;
    }
  }

  if (rightMotorActive) {
    if (millis() - rightMotorStartTime >= MOTOR_DURATION) {
      ledcWrite(MOTOR_RIGHT_PIN, PWM_DUTY_0);
      rightMotorActive = false;
    }
  }

  // 3. Manage Firmware Status LED Pulse
  if (fwLedActive) {
    if (millis() - fwLedStartTime >= FW_LED_DURATION) {
      digitalWrite(FIRMWARE_LED_PIN, LOW);
      fwLedActive = false;
    }
  }

  // 4. PREVENT FIFO BUFFER LOGJAM
  // FIX: Don't return after flush — reset state and let the parser loop continue.
  //      Also reset footerIndex which was previously missed.
  if (RadarSerial.available() > 512) {
    while (RadarSerial.available()) {
      RadarSerial.read();
    }
    currentState = SYNC_HEADER;
    headerIndex  = 0;
    footerIndex  = 0; // FIX: was missing, caused footer sync ghost matches after flush
    // No return — fall through to the parser which will now find nothing to read
  }

  // 5. Standard UART Stream Parsing State Machine
  while (RadarSerial.available()) {
    byte b = RadarSerial.read();

    switch (currentState) {
      case SYNC_HEADER:
        if (b == HEADER[headerIndex]) {
          headerIndex++;
          if (headerIndex == 4) {
            currentState = READ_LENGTH;
            headerIndex  = 0;
          }
        } else {
          headerIndex = (b == HEADER[0]) ? 1 : 0;
        }
        break;

      case READ_LENGTH:
        if (headerIndex == 0) {
          payloadLength = b; // Low byte
          headerIndex++;
        } else {
          payloadLength |= ((uint16_t)b << 8); // High byte
          headerIndex    = 0;
          if (payloadLength >= sizeof(payload)) {
            // FIX: Was '>' — this missed the exact boundary case.
            // >= correctly rejects frames that would overflow the buffer.
            currentState = SYNC_HEADER;
          } else if (payloadLength == 0) {
            // FIX: Mark payload as invalid before jumping to footer
            // so evaluateTargetThreat() doesn't process last frame's stale data
            payloadValid = false;
            currentState = SYNC_FOOTER;
          } else {
            payloadIndex = 0;
            currentState = READ_PAYLOAD;
          }
        }
        break;

      case READ_PAYLOAD:
        payload[payloadIndex++] = b;
        if (payloadIndex >= payloadLength) {
          payloadValid = true; // FIX: Mark this frame as fresh and complete
          currentState = SYNC_FOOTER;
        }
        break;

      case SYNC_FOOTER:
        if (b == FOOTER[footerIndex]) {
          footerIndex++;
          if (footerIndex == 4) {
            evaluateTargetThreat();
            currentState = SYNC_HEADER;
            footerIndex  = 0;
          }
        } else {
          currentState = SYNC_HEADER;
          footerIndex  = 0;
        }
        break;
    }
  }
}
